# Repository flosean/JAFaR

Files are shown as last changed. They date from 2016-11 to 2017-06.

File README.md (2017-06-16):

# Fork from JAFaR (Just Another Fatshark Receiver Module)

__DIY OpenSource 48ch receiver OSD integrated__

The aim of the project is to build an opensource 48ch receiver for Fatshark goggles which has to be easy to develop,
upgrade and maintain. And, of course, it must be cheap!
<p align="center">
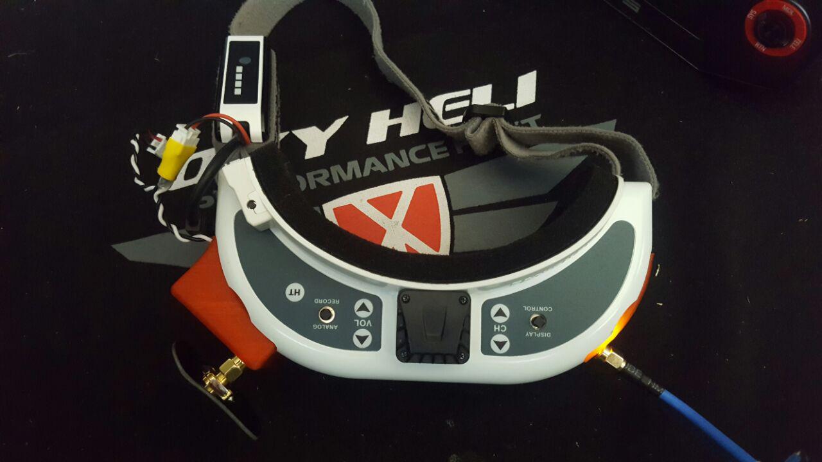
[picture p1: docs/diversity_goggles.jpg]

</p>

* 48ch (8 channels for 6 bands, including race band and low race band)
* No external switch, or hall effect sensor, or buzzer, it must use __only__ the goggles buttons (up-down)
* Auto search feature
* It should include the “scanner” feature (see recent project here https://github.com/MikyM0use/OLED-scanner)
* Frequency selection via OSD inside the goggles
* I tested it only with Fatshark HD but the module should work with every Fatshark with the RX external module (like Dominator V1, V2, V3, HD, HD2...)

This project uses the “RX5808” receiver module, which can be hacked to be SPI-programmed by a microcontroller (more details later).
So what I needed is a micro controller with an easy and well-know software IDE… nothing better than Arduino. So I decided to use an Atmega 328p as micro controller.

To select the frequency there's a series of menus on the screen inside the goggles, the
useful TVOUT Arduino library is perfect and requires just a couple of resistors
(http://playground.arduino.cc/Main/TVout).
A digital switch (TS5A3359) allow to switch from OSD to the normal receiving video from the quadcopter.

The project is mainly divided into two PCBs:
* one main base module
* one "diversity" daughterboard (optional)

it's also possible to use an SPI-OLED display and use the module as standalone RX.

##Table of contents
* [Main module](#main-module)
	* [DIY Instructions](#diy-instructions)
	* [MAIN MODULE Troubleshooting](#main-module-troubleshooting)
* [Diversity module](#diversity-module)
* [OLED module](#oled-module)
* [STANDALONE mode](#standalone-mode)
* [Reference thread](#reference-thread)
* [FAQ:](#faq)
* [Donations:](#donations)

##Main module

This is the main RX module, usable alone as a receiver module, but if you connect an
"external" module, the onboard microcontroller can decide which RX module has better
reception (so-called "diversity") based on the received signal strength. Indeed, this
RX5808 modules has an analog output called RSSI proportional on the "quality" of the
received video signal. The receiving video channel (frequency) is set by the user using an OSD menu.

<p align="center">


</p>

__MAIN MODULE (V4.1) BOM__

https://docs.google.com/spreadsheets/d/1CrZzOQHyK_d1VfHCQKwdNuoyMji0IYryI1VuffojdGA/edit?usp=sharing

__LEGACY MAIN MODULE (V3.2)__

This module is actually the same as the v4, but it doesn't have the buffer on the RSSI output,
and the PCB allows the use of a capacitor OR a resistor on the video out. DON'T use both! after some
tests I realized that a 10ohm resistor (and no cap) is enough.

<p align="center">

</p>

(the back side is the same of the v4.0).

__LEGACY MAIN MODULE (V3.2) BOM__

https://docs.google.com/spreadsheets/d/1-763imBV3QsQ71GKDZH-BirTz1k32szNuJZUKQrE00g/edit?usp=sharing

###DIY Instructions

1. Remove the shield of the RX5808 module and desolder the resistor marked by the arrow. This
is the SPI-mod required to control the module with an external microcontroller.

<p align="center">

</p>

2. Follow the instructions on the page https://www.arduino.cc/en/Tutorial/ArduinoISP to burn the bootloader (select __"Arduino Pro Mini 5v 16MHz"__ as target board)
using the pins in the upper right corner of the board

3. Use the FTDI connections in the left side of the board to upload the code present in the
Github page of the project. Please remember to copy all the subfolders of "libs" dir in the
libraries folder of Arduino (e.g. /Arduino/libraries).
Here you can find more infos and alternative methods to import the libraries:
https://www.arduino.cc/en/Guide/Libraries

4. When you power on the module, BOTH the leds (upper left corner of the pcb) must be on, and you must see a relatively stable splash screen for about 5 seconds

5. The very first time you power on the module, it need to calibrate itself. So please turn on the module with a working Vtx a couple of meter away (the video frequency doesn't matter). This process can take a while (about 30-50 seconds).

6. You can now use the "selection" buttons on the goggles to scroll up/down the menu to select the band

7. After the timeout of the countdown (upper left corner of the screen) you entered the frequency selection (of the selected band)

8. Scroll up/down to select the frequency and wait the timeout

9. At this moment only one led on the module has to be ON, it means that the RX video output is routed to the video_input of the goggles. If you have a Vtx near, you should see the video coming from it.

10. If you press the "selection" buttons of the goggles now, you change the frequency by the 8 frequencies of the previously selected band.

###MAIN MODULE Troubleshooting

After the initial calibration, the module must turn on in couple of seconds and you must see the splash screen for some seconds before the "band selection" screen.
In the "band selection" screen you can see the 5 bands with the percentage of the maximum RSSI detected on that band. At least one of the band must be at 98-100%.
If you "enter" one band, every channel must shows a different percentage of RSSI, otherwise the SPI-mod of the module could be failed.

__Unable to flash/Aduino issues:__

(thanks to pHysiX for the help in this section!)
Got the error "no reply" when trying to load the firmware:
the ATmega microcontroller is not soldered properly / there is a short on some pins.
try a quick solder, clean and reflow.

Got the error "incorrect signature" when trying to load the firmware:
This means Arduino is able to pick up the ATMega, but it was not communicating as expected.
This is related to poor soldering of the crystal. It's possible to do the crystal using
an iron, but I strongly recommend using flow method/hot air to do this, to make sure you
don't short the three legs accidentally onto the metal case.

__Display issues:__

They are mostly related to poor soldering for the OSD components on the board. Go back and
reflow especially the Switch, and then just make sure to clean up and touch up all the caps
and resistors near and around the switch.

If you have an external monitor, you can bypass the digital switch by power on the module with external 5v and connecting the "video in" of the monitor on the test point marked in yellow the picture:



and you should see the splash screen and the menu.

If you connect the "video in" of the monitor to the test point marked in green, you should see the initial scanning (used to determine the % of the RSSI on each channel), this means a sequence of different "fogs" and (at least) one "good" image (for a fraction of second), if you have a Vtx + cam transmitting.

__Frequency issues:__

If the module is having trouble Setting Frequency, or you are not getting video when you are
on the right channel and frequency, make sure the SPI mod has been done, and that the RX5808
is soldered on well. Pretty hard to mess this part up.

##Diversity module

The diversity module is an optional second receiver, connected to the "main" base module, it has:
* integrated linear 5v regulator with ENABLE feature connected to the VCC of the main module.
In fact power a second module from the internal goggles voltage regulator IS VERY DANGEROUS!
* an optional operational buffer for RSSI signal (I noticed that lately modules seems to be more delicate)

<p align="center">


</p>

Please notice that because of the linear regulator on the module, it's not possible to use a 3s battery to power the diversity module.

You have two options to connect the diversity module to the base module:
* by pins: putting diversity module on top of the base one
* by jst connector: following the schematic in the image below. I used a 8-pin JST because it's used also on some FC and it's more simple to find, even if only 7 pins are used.

<p align="center">
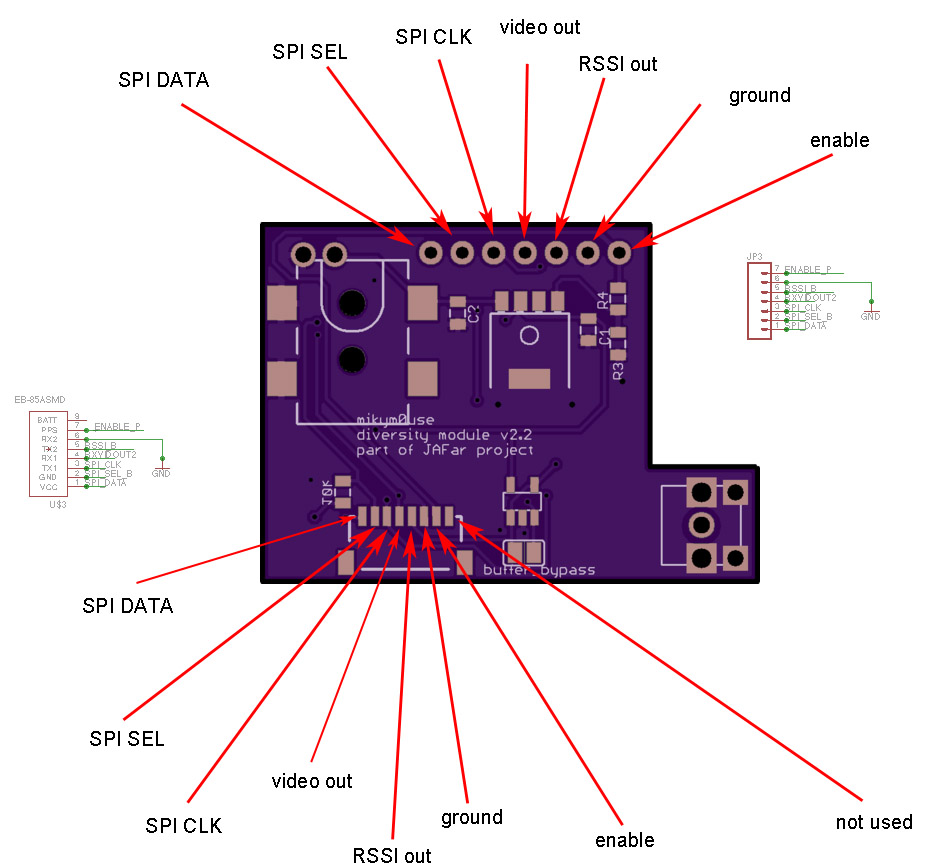
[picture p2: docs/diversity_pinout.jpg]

</p>

__DIVERSITY MODULE (V2.1) BOM__

https://docs.google.com/spreadsheets/d/1OpagubuxicmGTKqOHWwWdxZxY6wCs_DZqTYRxVoD4Tc/edit?usp=sharing

##OLED module
It's possible to use an external SPI OLED module in case of any problems with the internal OSD
or to use the module with an external monitor / different goggles.



It's important that the module has only SDA/SCL/RES/DC pins.

To use the OLED module instead of the internal OSD, uncomment  the line:

```
#define USE_OLED
```

in the file const.h

please remember to comment #define USE_DIVERSITY!

__Connections__

| ATMEGA328p pin |  PCB silkscreen name | OLED silkscreen name  |
| :---:	|:---:| :---:|
| VCC 				| 		EN 						| 		VCC 			|
| GND 				| GND 							| 					GND |
| 8 				| SSEL 							| 				SCL 	|
| A1 				| RSSI 					| 		SDA 		|
| A4 					|  NOT CONNECTED 			| 	NOT CONNECTED 	|
| 11 					| SDA 						| DC 				|
| 13				 	| CLK 						| RESET 				|

...or graphically:

<p align="center">

</p>

there's also a "PCB" inside the PCBs folder, but it's just a simple adapter.

##Standalone mode

It's possible to use the project also as a standalone receiver to be used in combination
with any external monitor or other kind of goggles.

In this case you must uncomment the line

```
#define STANDALONE
```

in the file const.h. You can use the standalone mode either with OSD or with the external OLED module.

to change band/channel, the connections are the following (every normally-open momentary switch will do the job):

<p align="center">

</p>

_UPDATE:_

it's now possible to use a "standalone module" to use the usually OSD menu on every monitor/goggles, look into /pcb/standalone_module

features:
a 5v BIG voltage regulator (up to 3/4s)
3.5mm jack output compatible with Fatshark pinout
up/down/enter joystick (work in progress to get the "back to the main menu" function by lon press the central button)
external battery /diversity module connection

<p align="center">
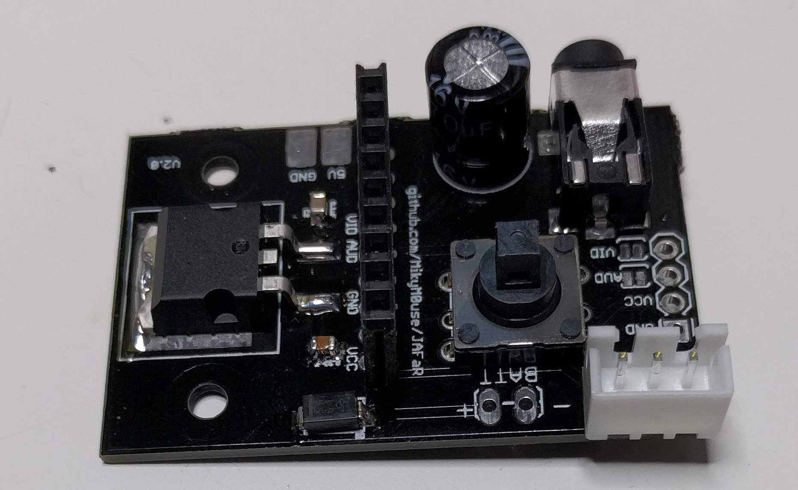
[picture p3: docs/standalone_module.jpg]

</p>

<p align="center">
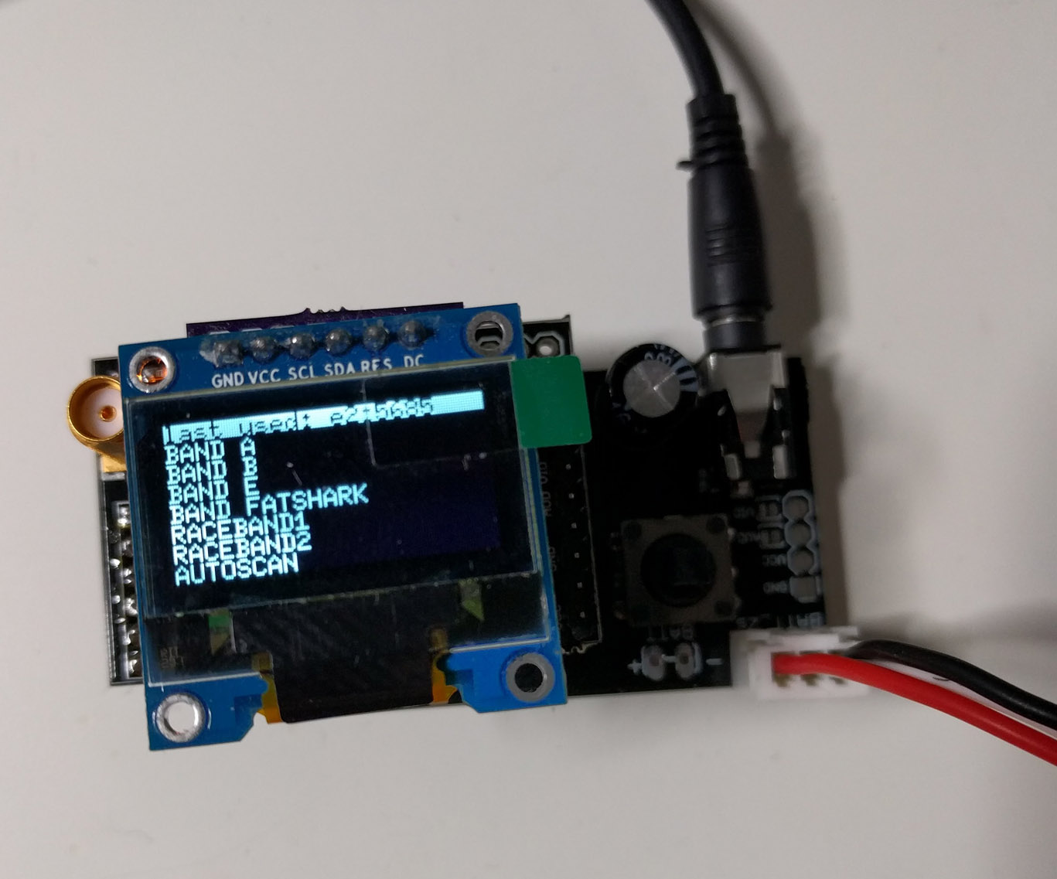
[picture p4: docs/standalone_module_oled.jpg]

</p>

<p align="center">
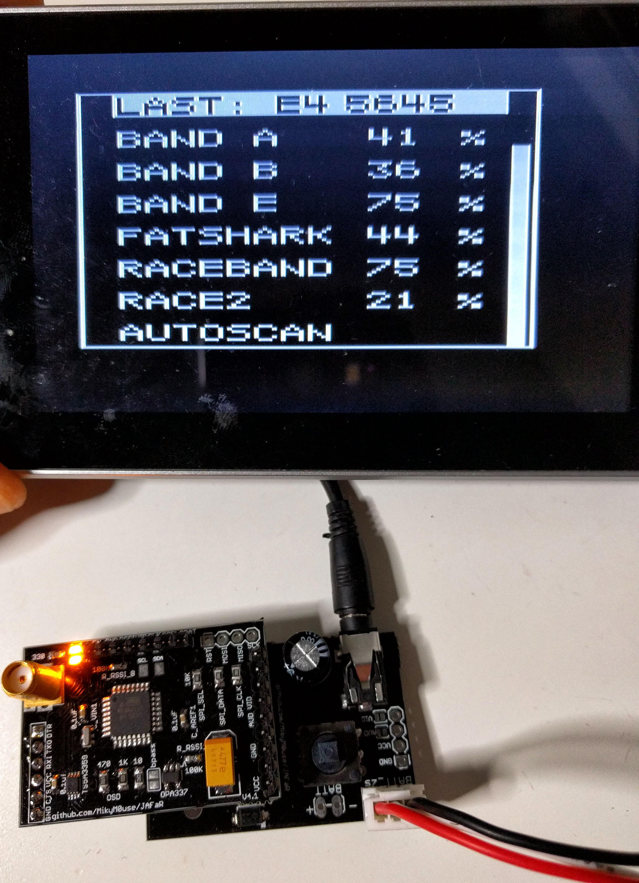
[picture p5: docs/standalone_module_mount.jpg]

</p>

__STANDALONE MODULE (V2.0) BOM__
https://docs.google.com/spreadsheets/d/1Lyl0Xg57OcXvrLwUwM6oeHDwdGa9hMxbpv7bcDlpDU4/edit?usp=sharing

##Reference thread

http://www.rcgroups.com/forums/showthread.php?t=2619124 while I'm still writing the readme :)

##FAQ

why the OSD is on the blank screen?
it’s simpler because one cannot have to recognize the vsync and the hsync pulses.

why the switch is so small and hard to solder?!?
I need a small 3-way switch, if you have a "simpler" one, just tell me :)

please note that you try and use this project AT YOUR OWN RISK!

##Donations

Hardware or paypal donations to carry on the project are always accepted.



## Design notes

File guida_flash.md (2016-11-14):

# Guida all'aggiornamento firmware del modulo

Per semplicità di spiegazione le immagini sono riferite a Windows, 
ma per Linux o Mac OSX il procedimento è analogo.

E' più semplice programmare il modulo utilizzando un normale convertitore "FTDI" a 6 pin 5V, ma
è possibile usare anche un semplice convertitore USB/Seriale collegando solo RX, TX e massa, ma 
bisognerà accendere il modulo appena dopo aver premuto il pulsante di programmazione, dato che 
il convertitore non sarà in grado di generare il segnale di reset.

Scaricare e installare l’ultima versione del software IDE Arduino dal sito:
https://www.arduino.cc/en/Main/Software

Scaricare ed estrarre dal .zip l’ultima release del firmware del modulo dal sito:
https://github.com/MikyM0use/JAFaR/releases

<p align="center">
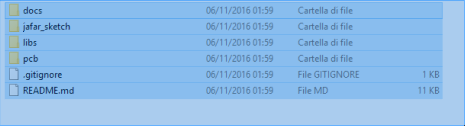
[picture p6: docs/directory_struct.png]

</p>

aprire il file "arduino\_sketch.ino" dentro alla cartella arduino\_sketch.

<p align="center">
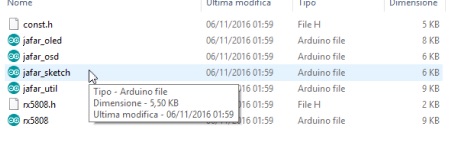
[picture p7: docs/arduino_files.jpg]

</p>

Se è la prima volta che si aggiorna il modulo, bisognerà installare le librerie:

<p align="center">
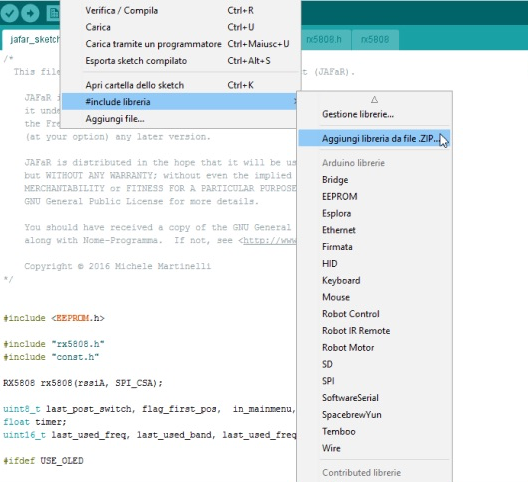
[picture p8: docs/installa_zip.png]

</p>

selezionare poi le tre cartelle (ripetendo il procedimento tre volte) contenute nella directory /libs
del file scaricato ed estratto da Github.

<p align="center">
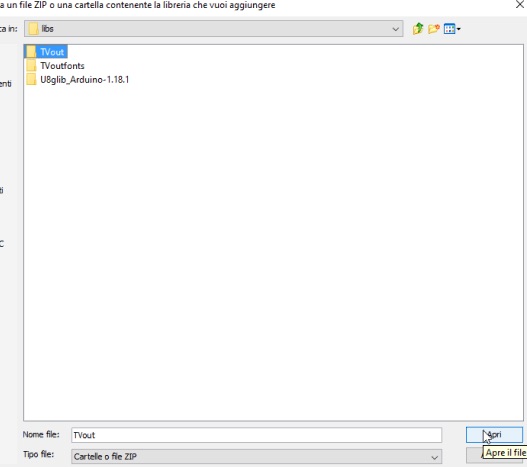
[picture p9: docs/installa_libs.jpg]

</p>

a questo punto selezionare il corretto tipo di board (Arduino pro o pro mini) e la porta (che dipende 
dal sistema operativo, *controllare che la porta sia corretta*)

<p align="center">
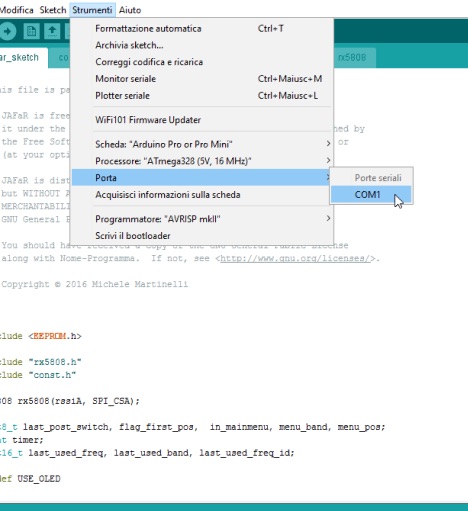
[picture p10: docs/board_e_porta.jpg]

</p>

effettuare le eventuali modifiche al software, poi collegare il modulo al convertitore FTDI (i
nomi dei pin sono scritti direttamente sul modulo, basta allineare i pin con il convertitore FTDI).

a questo punto premere il pulsante "carica" sull'IDE arduino e attendere il messaggio di "caricamento completato"

<p align="center">
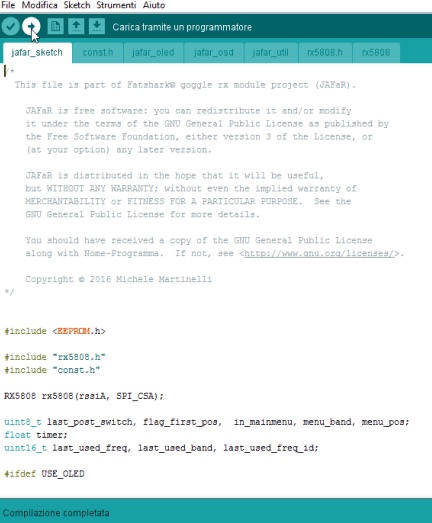
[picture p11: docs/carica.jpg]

</p>

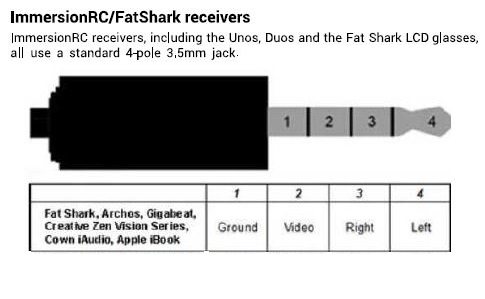
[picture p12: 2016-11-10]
pcb/standalone_module/goggle-pinout.jpg

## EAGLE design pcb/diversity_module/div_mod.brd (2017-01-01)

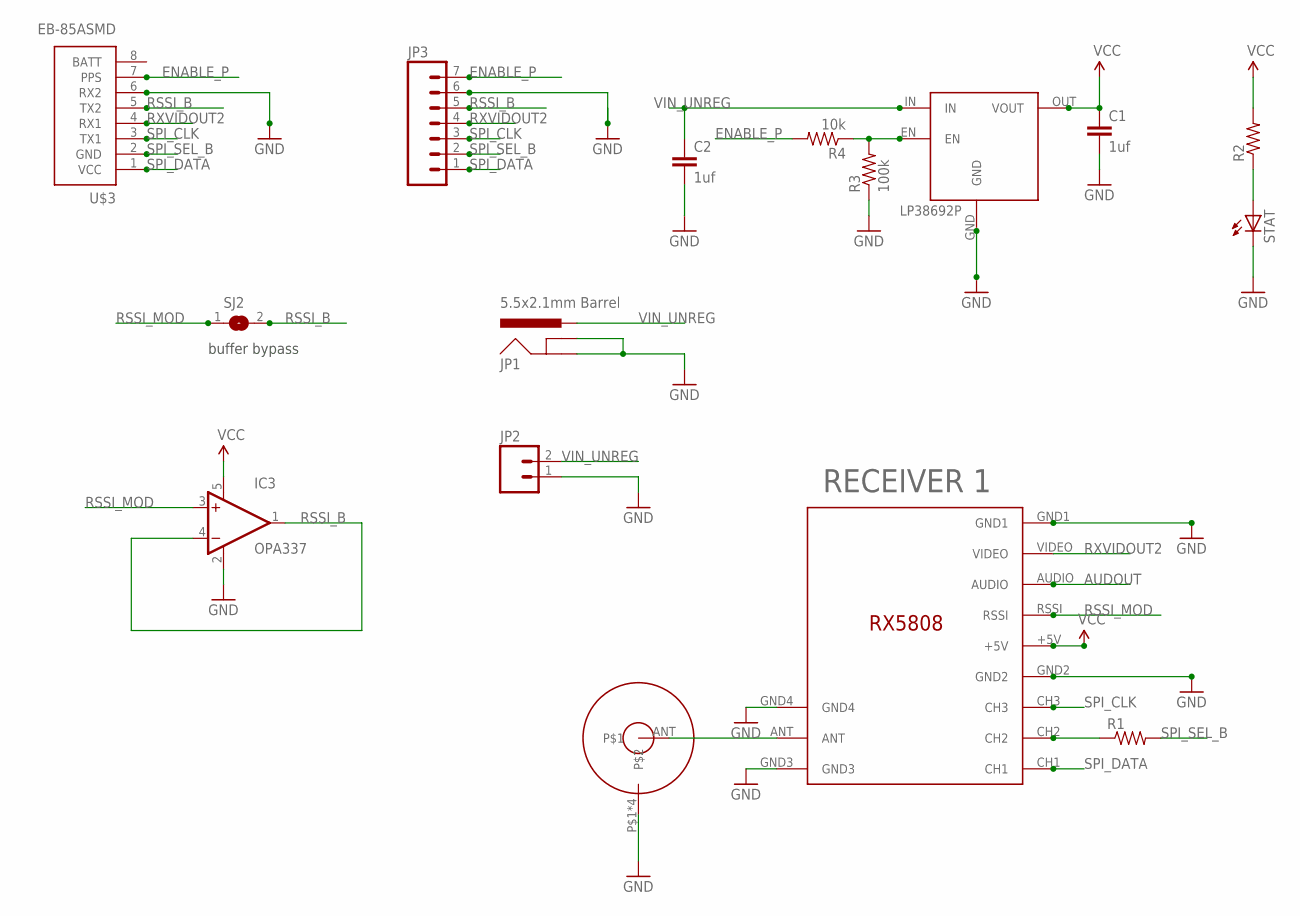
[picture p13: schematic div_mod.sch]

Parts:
C1, C2: 1uf; 0805
IC3: OPA336N; SOT23-5
JP1: 5.5x2.1mm Barrel; POWER_JACK_SMD
JP2: M02PTH; 1X02
JP3: M07; 1X07
R1, R2: RESISTOR0805-RES; 0805
R3: 100k; 0805
R4: 10k; 0805
RECEIVER_A: RX5808_A; RX5808
SJ2: SJ
STAT: LEDCHIP-LED0805; CHIP-LED0805
U$1: SMA_ANTENNA; SMA_CONNECTOR
U$3: EB-85ASMD; EB-85A
V1: LP38692P; TO252-51

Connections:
5V: C1.1, IC3.5 (V+), R2.2, RECEIVER_A.+5V, V1.OUT (VOUT)
AUDOUT: RECEIVER_A.AUDIO
BATT: U$3.8 (BATT)
ENABLE: R3.2, R4.1, V1.EN
ENABLE_P: JP3.7, R4.2, U$3.7 (PPS)
GND: C1.2, C2.2, IC3.2 (V-), JP1.GND (GNDBREAK), JP1.P$4 (GND), JP2.1, JP3.6, R3.1, RECEIVER_A.GND1, RECEIVER_A.GND2, RECEIVER_A.GND3, RECEIVER_A.GND4, STAT.C, U$1.P$1, U$1.P$2, U$1.P$3, U$1.P$4, U$3.6 (RX2), V1.GND
unnamed: R1.1, RECEIVER_A.CH2
unnamed: R2.1, STAT.A
unnamed: RECEIVER_A.ANT, U$1.ANT
RSSI_B: IC3.1 (OUT), IC3.4 (-IN), JP3.5, SJ2.2, U$3.5 (TX2)
RSSI_MOD: IC3.3 (+IN), RECEIVER_A.RSSI, SJ2.1
RXVIDOUT2: JP3.4, RECEIVER_A.VIDEO, U$3.4 (RX1)
SPI_CLK: JP3.3, RECEIVER_A.CH3, U$3.3 (TX1)
SPI_DATA: JP3.1, RECEIVER_A.CH1, U$3.1 (VCC)
SPI_SEL_B: JP3.2, R1.2, U$3.2 (GND)
VIN_UNREG: C2.1, JP1.VIN0 (PWR), JP2.2, V1.IN

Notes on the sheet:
RECEIVER 1
buffer bypass
OPA337

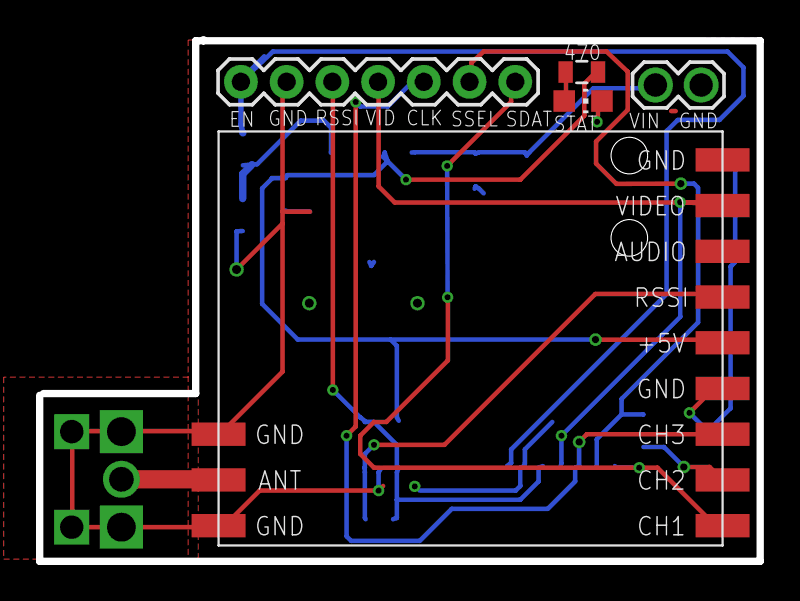
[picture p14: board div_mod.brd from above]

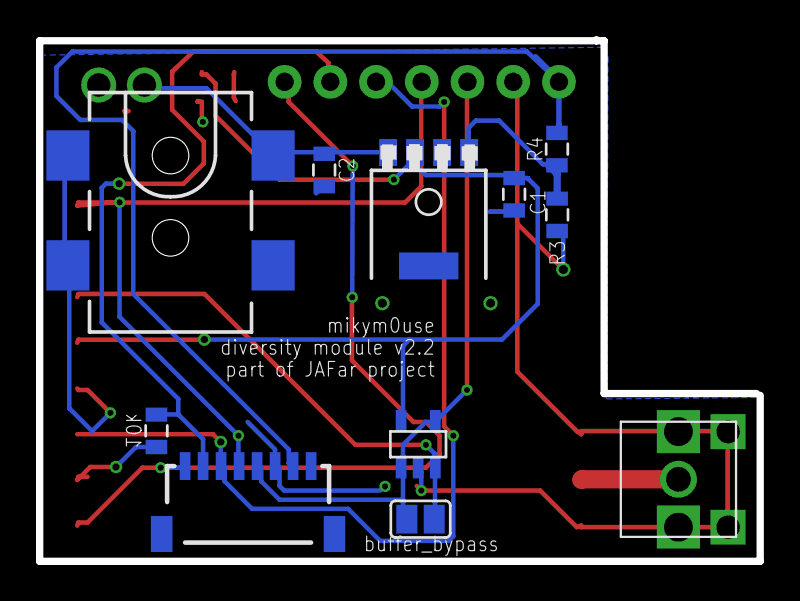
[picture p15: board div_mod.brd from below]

Board: 2 copper layers, 40.0 x 28.9 mm, 16 parts (11 on the bottom side), 14 nets.

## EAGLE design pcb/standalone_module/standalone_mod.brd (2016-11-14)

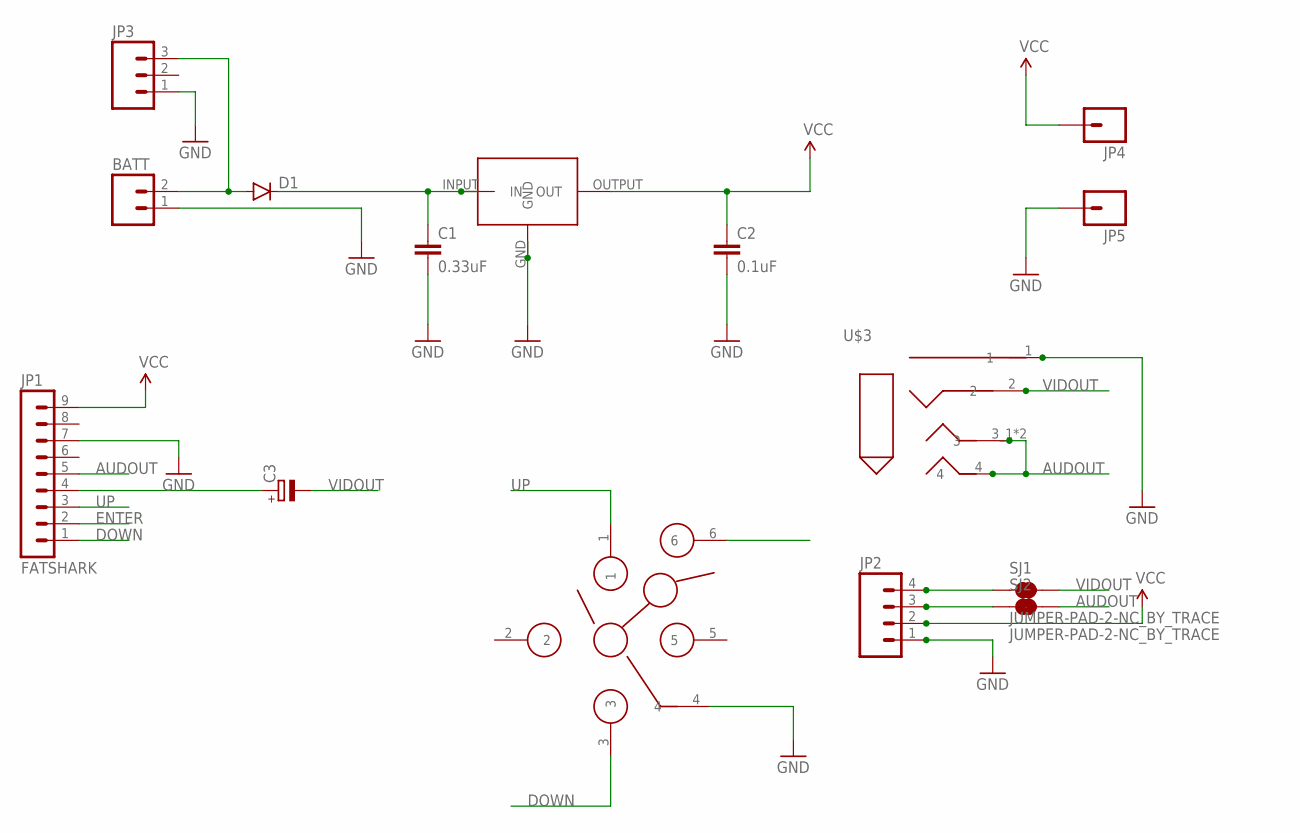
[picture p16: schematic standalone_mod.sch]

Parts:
BATT: M02LOCK_LONGPADS; 1X02_LOCK_LONGPADS
C1: 0.33uF; 0805
C2: 0.1uF; 0805
C3: CPOL-EUE3.5-8; E3,5-8
D1: DIODESMA; SMA-DIODE
JP1: FATSHARK; MA09-1
JP2: M04PTH; 1X04
JP3: M03LONGPADS; 1X03_LONGPADS
JP4, JP5: M01SMD; LUXEON-PAD
SJ1, SJ2: JUMPER-PAD-2-NC_BY_TRACE; PAD-JUMPER-2-NC_BY_TRACE_YES_SILK
U$1: 7805; DDPAK
U$2: SKQUCAA010
U$3: MC001293JACK; MC001293

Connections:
5V: C2.1, JP1.9, JP2.2, JP4.P$1, U$1.OUTPUT (OUT)
AUDOUT: JP1.5, SJ2.2, U$3.3_1 (3), U$3.3_2 (3), U$3.4
DOWN: JP1.1, U$2.3
ENTER: JP1.2, U$2.6
GND: BATT.1, C1.2, C2.2, JP1.7, JP2.1, JP3.1, JP5.P$1, U$1.GND, U$2.4, U$3.1
unnamed: C1.1, D1.C, U$1.INPUT (IN)
unnamed: C3.+, JP1.4
unnamed: BATT.2, D1.A, JP3.3
unnamed: JP2.4, SJ1.1
unnamed: JP2.3, SJ2.1
UP: JP1.3, U$2.1
VIDOUT: C3.-, SJ1.2, U$3.2

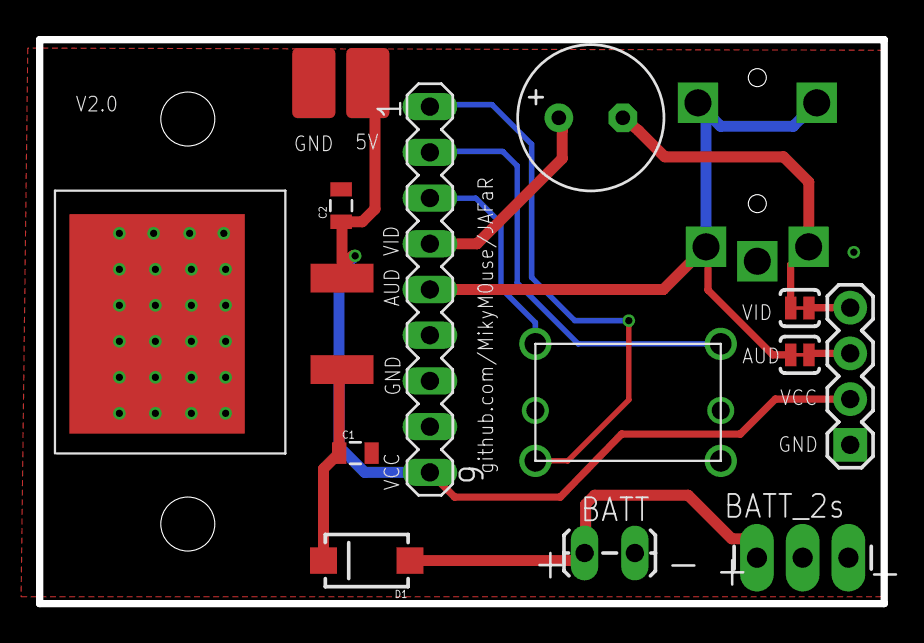
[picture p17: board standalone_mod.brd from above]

Board: 2 copper layers, 46.9 x 31.3 mm, 15 parts (0 on the bottom side), 12 nets.

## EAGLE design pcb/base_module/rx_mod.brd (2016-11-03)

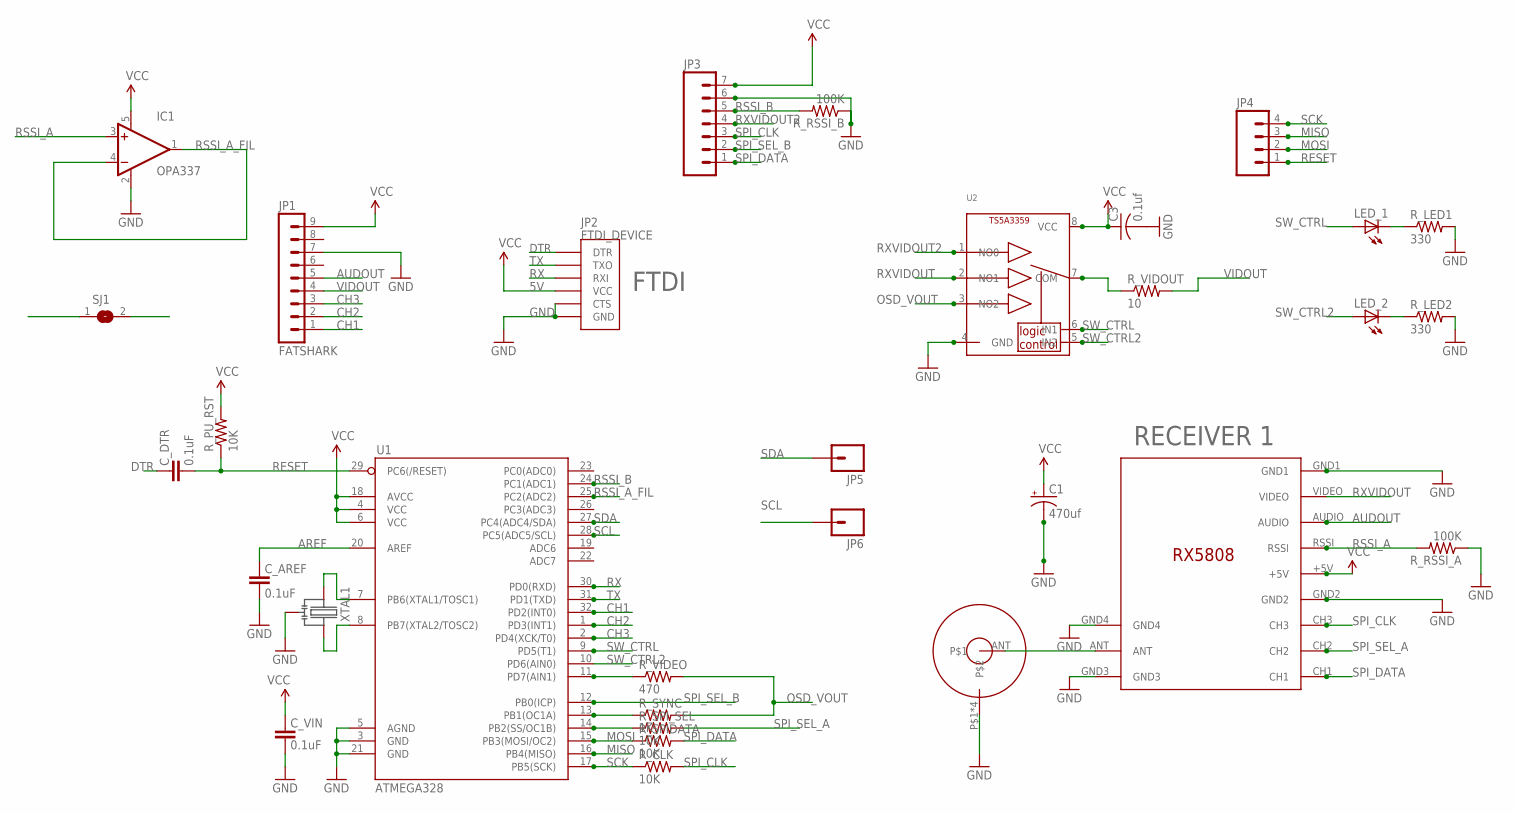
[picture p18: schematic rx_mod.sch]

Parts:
C1: 470uf; EIA7343
C3: 0.1uf; C0603
C_AREF: 0.1uF; 0603-CAP
C_DTR: 0.1uF; 0603-CAP
C_VIN: 0.1uF; 0603-CAP
IC1: OPA336N; SOT23-5
JP1: FATSHARK; MA09-1
JP2: FTDI_DEVICE; FTDI_DEVICE_SIDE
JP3: M07; 1X07
JP4: M04PTH; 1X04
JP5, JP6: M01SMD-4.5X1.5; PAD-1.5X4.5
LED_1, LED_2: LEDSML0603; SML0603
RECEIVER_A: RX5808_A; RX5808
R_CLK: 10K; R0805
R_LED1, R_LED2: 330; R0603
R_PU_RST: 10K; 0603-RES
R_RSSI_A: 100K; 0603-RES
R_RSSI_B: 100K; 0603-RES
R_SPIDATA: 10K; R0805
R_SPI_SEL: 10K; R0805
R_SYNC: 1K; R0805
R_VIDEO: 470; R0805
R_VIDOUT: 10; R0805
SJ1: SJ
U1: ATMEGA328; TQFP32-08
U2: TS5A3359; VFSOP-8
U$1: SMA_ANTENNA; SMA_CONNECTOR
XTAL1: CSTCE16M0V53-R0

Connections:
5V: C1.A (+), C3.1, C_VIN.2, IC1.5 (V+), JP1.9, JP2.P$4 (VCC), JP3.7, RECEIVER_A.+5V, R_PU_RST.2, U1.4 (VCC), U1.6 (VCC), U1.18 (AVCC), U2.8 (VCC)
AREF: C_AREF.2, U1.20 (AREF)
AUDOUT: JP1.5, RECEIVER_A.AUDIO
CH1: JP1.1, U1.32 (PD2(INT0))
CH2: JP1.2, U1.1 (PD3(INT1))
CH3: JP1.3, U1.2 (PD4(XCK/T0))
DTR: C_DTR.2, JP2.P$1 (DTR)
GND: C1.C (-), C3.2, C_AREF.1, C_VIN.1, IC1.2 (V-), JP1.7, JP2.P$5 (CTS), JP2.P$6 (GND), JP3.6, RECEIVER_A.GND1, RECEIVER_A.GND2, RECEIVER_A.GND3, RECEIVER_A.GND4, R_LED1.2, R_LED2.2, R_RSSI_A.1, R_RSSI_B.1, U1.3 (GND), U1.5 (AGND), U1.21 (GND), U2.4 (GND), U$1.P$1, U$1.P$2, U$1.P$3, U$1.P$4, XTAL1.2
MISO: JP4.3, U1.16 (PB4(MISO))
MOSI: JP4.2, R_SPIDATA.1, U1.15 (PB3(MOSI/OC2))
unnamed: U1.8 (PB7(XTAL2/TOSC2)), XTAL1.3
unnamed: U1.7 (PB6(XTAL1/TOSC1)), XTAL1.1
unnamed: LED_1.C, R_LED1.1
unnamed: R_SPI_SEL.1, U1.14 (PB2(SS/OC1B))
unnamed: RECEIVER_A.ANT, U$1.ANT
unnamed: R_VIDOUT.1, U2.7 (COM)
unnamed: R_SYNC.1, U1.13 (PB1(OC1A))
unnamed: R_VIDEO.1, U1.11 (PD7(AIN1))
unnamed: LED_2.C, R_LED2.1
OSD_VOUT: R_SYNC.2, R_VIDEO.2, U2.3 (NO2)
RESET: C_DTR.1, JP4.1, R_PU_RST.1, U1.29 (PC6(/RESET))
RSSI_A: IC1.3 (+IN), RECEIVER_A.RSSI, R_RSSI_A.2, SJ1.1
RSSI_A_FIL: IC1.1 (OUT), IC1.4 (-IN), SJ1.2, U1.25 (PC2(ADC2))
RSSI_B: JP3.5, R_RSSI_B.2, U1.24 (PC1(ADC1))
RX: JP2.P$3 (RXI), U1.30 (PD0(RXD))
RXVIDOUT: RECEIVER_A.VIDEO, U2.2 (NO1)
RXVIDOUT2: JP3.4, U2.1 (NO0)
SCK: JP4.4, R_CLK.1, U1.17 (PB5(SCK))
SCL: JP6.P$1, U1.28 (PC5(ADC5/SCL))
SDA: JP5.P$1, U1.27 (PC4(ADC4/SDA))
SPI_CLK: JP3.3, RECEIVER_A.CH3, R_CLK.2
SPI_DATA: JP3.1, RECEIVER_A.CH1, R_SPIDATA.2
SPI_SEL_A: RECEIVER_A.CH2, R_SPI_SEL.2
SPI_SEL_B: JP3.2, U1.12 (PB0(ICP))
SW_CTRL: LED_1.A, U1.9 (PD5(T1)), U2.6 (IN1)
SW_CTRL2: LED_2.A, U1.10 (PD6(AIN0)), U2.5 (IN2)
TX: JP2.P$2 (TXO), U1.31 (PD1(TXD))
VIDOUT: JP1.4, R_VIDOUT.2

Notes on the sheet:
RECEIVER 1
FTDI
OPA337

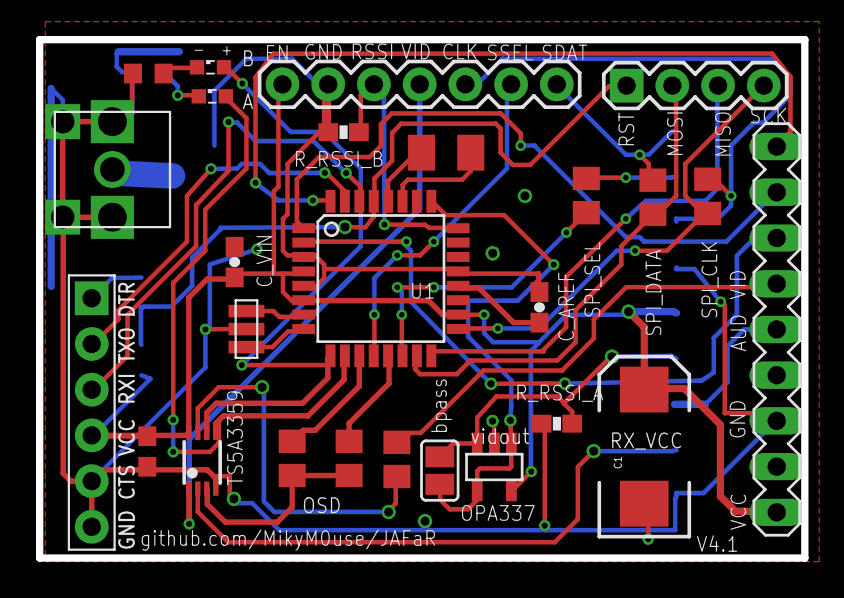
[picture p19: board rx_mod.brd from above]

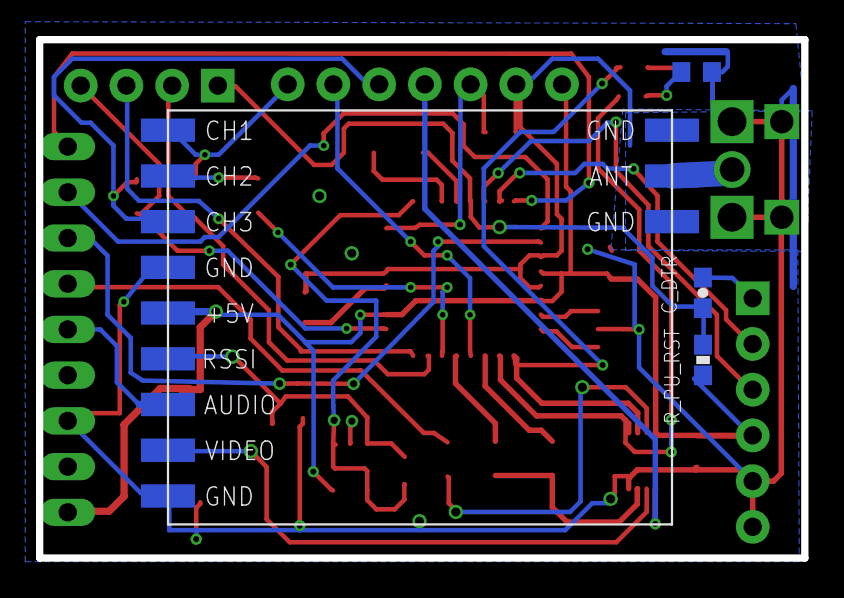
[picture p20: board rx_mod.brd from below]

Board: 2 copper layers, 42.5 x 28.8 mm, 31 parts (4 on the bottom side), 38 nets.

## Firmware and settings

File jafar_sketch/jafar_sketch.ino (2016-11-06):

/*
  This file is part of Fatshark© goggle rx module project (JAFaR).

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
    Copyright © 2016 Michele Martinelli
*/


#include <EEPROM.h>

#include "rx5808.h"
#include "const.h"

RX5808 rx5808(rssiA, SPI_CSA);

uint8_t last_post_switch, flag_first_pos,  in_mainmenu, menu_band, menu_pos;
float timer;
uint16_t last_used_freq, last_used_band, last_used_freq_id;

#ifdef USE_OLED

#include "U8glib.h"

#ifdef USE_I2C_OLED
U8GLIB_SSD1306_128X64 u8g(U8G_I2C_OPT_DEV_0 | U8G_I2C_OPT_NO_ACK | U8G_I2C_OPT_FAST); // Fast I2C / TWI
#else
U8GLIB_SSD1306_128X64 u8g(8, A1, A4, 11 , 13); //CLK, MOSI, CS, DC, RESET
#endif

char j_buf[80];

#endif
#ifdef USE_OSD

#include <TVout.h>
#include <fontALL.h>

TVout TV;

#endif //USE OSD

void inline jafar_delay(const uint16_t __delay) {
#ifdef USE_OSD
  TV.delay(__delay);
#else
  delay(__delay);
#endif
}

//////********* SETUP ************////////////////////
void setup() {

#ifdef STANDALONE
  pinMode(CH1, INPUT_PULLUP); //UP
  pinMode(CH2, INPUT_PULLUP); //ENTER
  pinMode(CH3, INPUT_PULLUP); //DOWN
#endif
  //menu_pos = 5;

  //video out init
  pinMode(SW_CTRL1, OUTPUT);
  pinMode(SW_CTRL2, OUTPUT);
  SELECT_OSD;

  //initialize SPI
  pinMode(spiDataPin, OUTPUT);
  pinMode(spiClockPin, OUTPUT);

  //RX module init
  rx5808.init();
  //rx5808.calibration();

#ifdef USE_OLED
  oled_init();
#endif
#ifdef USE_OSD
  osd_init();
#endif

#ifdef DEBUG
  Serial.begin(9600);
  Serial.println("HELLO WORLD\n");

  int i = 0;
  Serial.print("get rssi per band:");
  for (i = 0; i < NUM_BANDS; i++) {
    Serial.println(rx5808.getMaxValBand(i, 7), DEC);
  }
  Serial.println("");
#endif

  flag_first_pos = 0;
#ifdef FORCE_FIRST_MENU_ITEM
  flag_first_pos = readSwitch();
  last_post_switch = 0;
#else
  last_post_switch = -1; //init menu position
#endif

  in_mainmenu = 1;
  timer = TIMER_INIT_VALUE;

  //load last used values
  last_used_band = EEPROM.read(EEPROM_ADDR_LAST_BAND_ID); //channel name
  last_used_freq_id = EEPROM.read(EEPROM_ADDR_LAST_FREQ_ID);
  last_used_freq = pgm_read_word_near(channelFreqTable + (8 * last_used_band) + last_used_freq_id); //freq

#ifdef USE_I2C_OLED  //default - set the last freq
  rx5808.setFreq(last_used_freq); //set the last freq
#endif

  _init_selection = readSwitch();
}

void autoscan() {
  int reinit = 1; //only the first time, re-init the oled
  last_post_switch = -1; //force first draw
  timer = TIMER_INIT_VALUE;
  rx5808.scan(); //refresh RSSI
  rx5808.compute_top8();

  while (timer) {
    menu_pos = readSwitch();

    if (menu_pos != last_post_switch)  //user moving
      timer = TIMER_INIT_VALUE;

#ifdef USE_OLED
    oled_autoscan(reinit);
    reinit = 0;
#endif
#ifdef USE_OSD
    osd_autoscan();
#endif

    last_post_switch = menu_pos;

    jafar_delay(LOOPTIME);
    timer -= (LOOPTIME / 1000.0);
  }

  set_and_wait((rx5808.getfrom_top8(menu_pos) & 0b11111000) / 8, rx5808.getfrom_top8(menu_pos) & 0b111);
}

#ifdef USE_SCANNER
void scanner_mode() {

#ifdef USE_OLED
  oled_scanner();
#endif
#ifdef USE_OSD
  osd_scanner();
#endif

  timer = TIMER_INIT_VALUE;
}
#endif

void loop(void) {
  uint8_t i;

  menu_pos = readSwitch();

  //force always the first menu item (last freq used)
#ifdef FORCE_FIRST_MENU_ITEM
  if (flag_first_pos == menu_pos)
    menu_pos = _init_selection = 0;
#endif

  //new user selection
  if (last_post_switch != menu_pos) {
    flag_first_pos = 0;
    timer = TIMER_INIT_VALUE;
#ifdef STANDALONE //debounce
    jafar_delay(JAFARE_DEBOUCE_TIME);
#endif
#ifdef USE_I2C_OLED //changing freq every pression
    if (!in_mainmenu)
      rx5808.setFreq(pgm_read_word_near(channelFreqTable + (8 * menu_band) + menu_pos));
#endif
  }
#ifndef STANDALONE //no timer in standalone
  else {
    timer -= (LOOPTIME / 1000.0);
  }
#endif

  last_post_switch = menu_pos;

  if (timer <= 0) { //end of time for selection

    if (in_mainmenu) { //switch from menu to submenu (band -> frequency)
      if (menu_pos == compute_position(LAST_USED_POS)) //LAST USED
        set_and_wait(last_used_band, last_used_freq_id);

#ifdef USE_SCANNER
      else if (menu_pos == compute_position(SCANNER_POS)) //SCANNER
        scanner_mode();
#endif
      else if (menu_pos == compute_position(AUTOSCAN_POS)) //AUTOSCAN
        autoscan();
      else {
        in_mainmenu = 0;
        menu_band = ((menu_pos - 1 - _init_selection + 8) % 8);
#ifdef USE_I2C_OLED
        set_and_wait(menu_band, menu_pos);
#else
        timer = TIMER_INIT_VALUE;
#endif
      }

      jafar_delay(200);

    } else { //if in submenu
      //after selection of band AND freq by the user
      timer = 0;
      set_and_wait(menu_band, menu_pos);
    } //else
  } //timer

  //time still running
  if (in_mainmenu) { //on main menu
#ifdef USE_OLED
    oled_mainmenu(menu_pos);
#endif
#ifdef USE_OSD
    osd_mainmenu(menu_pos) ;
#endif
  } else { //on submenu
#ifdef USE_OLED
    oled_submenu(menu_pos,  menu_band);
#endif
#ifdef USE_OSD
    osd_submenu(menu_pos,  menu_band);
#endif
  }
  jafar_delay(LOOPTIME);
}

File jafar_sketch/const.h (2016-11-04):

/*
This file is part of Fatshark© goggle rx module project (JAFaR).

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
    Copyright © 2016 Michele Martinelli
  */

#ifndef const_h
#define const_h

#define FORCE_FIRST_MENU_ITEM //force always the first menu item (last freq used)
//#define STANDALONE //NO GOGGLES - TO BE TESTED

//ONLY ONE OF THE FOLLOWING:
#define USE_DIVERSITY
//#define USE_OLED

//uncomment this to use the I2C OLED version (PCB 4.1 beta)
//#define USE_I2C_OLED

//ONLY ONE OF THE FOLLOWING:
#define USE_48CH
//#define USE_SCANNER


#define CHANNEL_MIN 0
#ifdef USE_48CH
#define NUM_BANDS 6
#define CHANNEL_MAX 48
#else
#define NUM_BANDS 5
#define CHANNEL_MAX 40
#endif



//DEBUG STUFF
//#define DEBUG //to use this: force_first, OLED disabeld, OSD disabled, DEBUG enabled
//#define ENABLE_RSSILOG
#define FLIP_SCREEN

#ifndef USE_OLED
#define USE_OSD //comment this just for debug
#endif


#ifdef STANDALONE
#define LOOPTIME 100
#else
#define LOOPTIME 1000
#endif

#define JAFARE_DEBOUCE_TIME 180

#define TIMER_INIT_VALUE 5.0
#define CH1 2
#define CH2 3
#define CH3 4

//calibration stored values
#define EEPROM_ADR_RSSI_MIN_L 2
#define EEPROM_ADR_RSSI_MIN_H 3
#define EEPROM_ADR_RSSI_MAX_L 4
#define EEPROM_ADR_RSSI_MAX_H 5

#define EEPROM_ADDR_LAST_BAND_ID 15
#define EEPROM_ADDR_LAST_FREQ_ID 16

#define EEPROM_ADDR_START_LOG 20

#define RX_A 1
#define RX_B 0

//diplay dependant
#define D_COL 120
#define D_ROW 96
#define MENU_Y_SIZE 12

//SPI related
#define spiDataPin 11
#define spiClockPin 13

#define SPI_CSA 10//receiver SPI Select pin
#define rssiA A2  //RSSI input

#define SPI_CSB 8//receiver SPI Select pin
#define rssiB A1  //RSSI input

#define SW_CTRL1 5
#define SW_CTRL2 6

//#define BUZPIN 0 //digitalWrite(BUZPIN, HIGH);TV.delay(50);digitalWrite(BUZPIN, LOW);pinMode(BUZPIN, OUTPUT); //UP digitalWrite(BUZPIN,LOW);
#define SELECT_OSD {digitalWrite(SW_CTRL1, HIGH);digitalWrite(SW_CTRL2, HIGH);}
#define SELECT_A {digitalWrite(SW_CTRL1, LOW);  digitalWrite(SW_CTRL2, HIGH);}
#define SELECT_B {digitalWrite(SW_CTRL1, HIGH);  digitalWrite(SW_CTRL2, LOW);}

#define RX_HYST 0 //~10%

// Channels with their Mhz Values
const uint16_t channelFreqTable[] PROGMEM = {
  // Channel 1 - 8
  5865, 5845, 5825, 5805, 5785, 5765, 5745, 5725, // Band A
  5733, 5752, 5771, 5790, 5809, 5828, 5847, 5866, // Band B
  5705, 5685, 5665, 5645, 5885, 5905, 5925, 5945, // Band E
  5740, 5760, 5780, 5800, 5820, 5840, 5860, 5880, // Band F / Airwave
  5658, 5695, 5732, 5769, 5806, 5843, 5880, 5917, // Raceband 1
  5362, 5399, 5436, 5473, 5510, 5547, 5584, 5621  // Raceband 2
};

// All Channels of the above List ordered by Mhz
const uint8_t channelList[] PROGMEM = {
  19, 32, 18, 17, 33, 16, 7, 34, 8, 24, 6, 9, 25, 5, 35, 10, 26, 4, 11, 27, 3, 36, 12, 28, 2, 13, 29, 37, 1, 14, 30, 0, 15, 31, 38, 20, 21, 39, 22, 23
};

const uint8_t channelNames[] PROGMEM = {
  0xA1, 0xA2, 0xA3, 0xA4, 0xA5, 0xA6, 0xA7, 0xA8,
  0xB1, 0xB2, 0xB3, 0xB4, 0xB5, 0xB6, 0xB7, 0xB8,
  0xE1, 0xE2, 0xE3, 0xE4, 0xE5, 0xE6, 0xE7, 0xE8,
  0xF1, 0xF2, 0xF3, 0xF4, 0xF5, 0xF6, 0xF7, 0xF8,
  0xC1, 0xC2, 0xC3, 0xC4, 0xC5, 0xC6, 0xC7, 0xC8,
  0xD1, 0xD2, 0xD3, 0xD4, 0xD5, 0xD6, 0xD7, 0xD8
};

//menu entry positions
#define NUM_MENU_ITEMS 8

#define  LAST_USED_POS 0
#define  BAND_A_POS 1
#define  BAND_B_POS 2
#define  BAND_E_POS 3
#define  BAND_F_POS 4
#define  BAND_R1_POS 5
#define  BAND_R2_POS 6
#define  SCANNER_POS 6
#define  AUTOSCAN_POS 7

uint8_t _init_selection;

uint8_t inline compute_position(const uint8_t _pos) {
  return ((_init_selection + _pos) % NUM_MENU_ITEMS);
}
#endif

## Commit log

2016-10-18 pcb oled
    [rx_mod.brd, rx_mod.sch]
2016-10-18 switch const.h to default 48ch for testing
2016-10-24 solved issue with IDE > 1.6.9
    [jafar_sketch.ino, rx5808.ino]
2016-10-27 standalone module V1.0 first commit
    [standalone_mod.brd, standalone_mod.sch]
2016-10-27 new V4.1 base module (I2C OLED pins exposed + some bug fix)
    [rx_mod.brd, rx_mod.sch]
2016-10-27 add calibration of B module
2016-10-27 add dynamic menu creation - based on the goggles switch position
2016-10-28 fix a bug with dynamic computation of diversity RSSI min value and free some ram
    [const.h, jafar_osd.ino, jafar_util.ino]
2016-10-29 compute_position - field tested - TODO: better filter on diversity
2016-10-30 diversity filter - first draft to test
2016-11-04 small bugs fix in case of STANDALONE
    [const.h, jafar_oled.ino, jafar_sketch.ino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]
2016-11-10 standalone v2.0
    [standalone_mod.brd, standalone_mod.sch]
2016-11-10 diversity module v2.2 - better traces and big holes for battery
    [div_mod.brd, div_mod.sch]
2016-11-14 standalone module v2
    [standalone_mod.brd, standalone_mod.sch]
2017-01-01 div mod updates
    [div_mod.brd, div_mod.sch]

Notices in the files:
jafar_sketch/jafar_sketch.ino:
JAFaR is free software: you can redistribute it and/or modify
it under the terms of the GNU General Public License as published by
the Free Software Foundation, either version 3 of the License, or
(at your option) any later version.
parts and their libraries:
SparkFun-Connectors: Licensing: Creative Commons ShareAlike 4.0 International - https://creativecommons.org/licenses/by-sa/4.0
